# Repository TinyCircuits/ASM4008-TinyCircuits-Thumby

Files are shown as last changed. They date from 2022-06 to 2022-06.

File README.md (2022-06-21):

# ASM4008 TinyCircuits Thumby

The design files are located under design_files/ for the TinyCircuits ASM4008 PCB. *Note: Rev 6 is the latest and current version of Thumby being built and shipped. Early Kickstarter units shipped with Rev 5 Thumby hardware - Rev 6 updates were made during fulfillment to decrease manufacturing and assembly time.* This is a RP2040 board that is programmable using Arduino, Thonny, or any preferred MicroPython IDE. We recommend using our web browser [Thumby Code Editor](https://code.thumby.us/) for MicroPython.

Format is in Cadsoft Eagle format - Eagle version 6.2 was used for the original design.

For more infomation, check out the [Thumby product page](https://tinycircuits.com/thumby) at TinyCircuits.com

Other helpful Thumby Links:

- [Thumby Documentation Site](https://thumby.us/)  
   -  Contribute to Thumby Documentation at the [Thumby Doc Site Repository](https://github.com/TinyCircuits/Thumby-Website)
- [Thumby Code Editor](https://code.thumby.us/)
   - Contrbute to the [Thumby Code Editor Repository](https://github.com/TinyCircuits/TinyCircuits-Thumby-Code-Editor)
- [Thumby Arcade](https://arcade.thumby.us/)
   - Contribute a game to the [Thumby Game Repository](https://github.com/TinyCircuits/TinyCircuits-Thumby-Games)

# License:

Design by TinyCircuits.
All design files are released under the Creative Commons Attribution Share-Alike 3.0 License, see the following link for details: http://creativecommons.org/licenses/by-sa/3.0

All text above must be included in any redistribution or derived design

This project uses designs and concepts developed as part of the Arduino project and the LilyPad project.  The TinyCircuits design files themselves (schematics, PCB and libraries) are not directly derived from these works' design files and have been created new, however the concepts and basic architecture behind the TinyDuino and TinyLily products are derived and we thank the hard work of the organizations below for their contributions to open-source hardware:
  
Original Arduino Uno Design by Team Arduino

LilyPad Arduino Design by Leah Buechley and Sparkfun Electronics

Please support the open-source hardware community

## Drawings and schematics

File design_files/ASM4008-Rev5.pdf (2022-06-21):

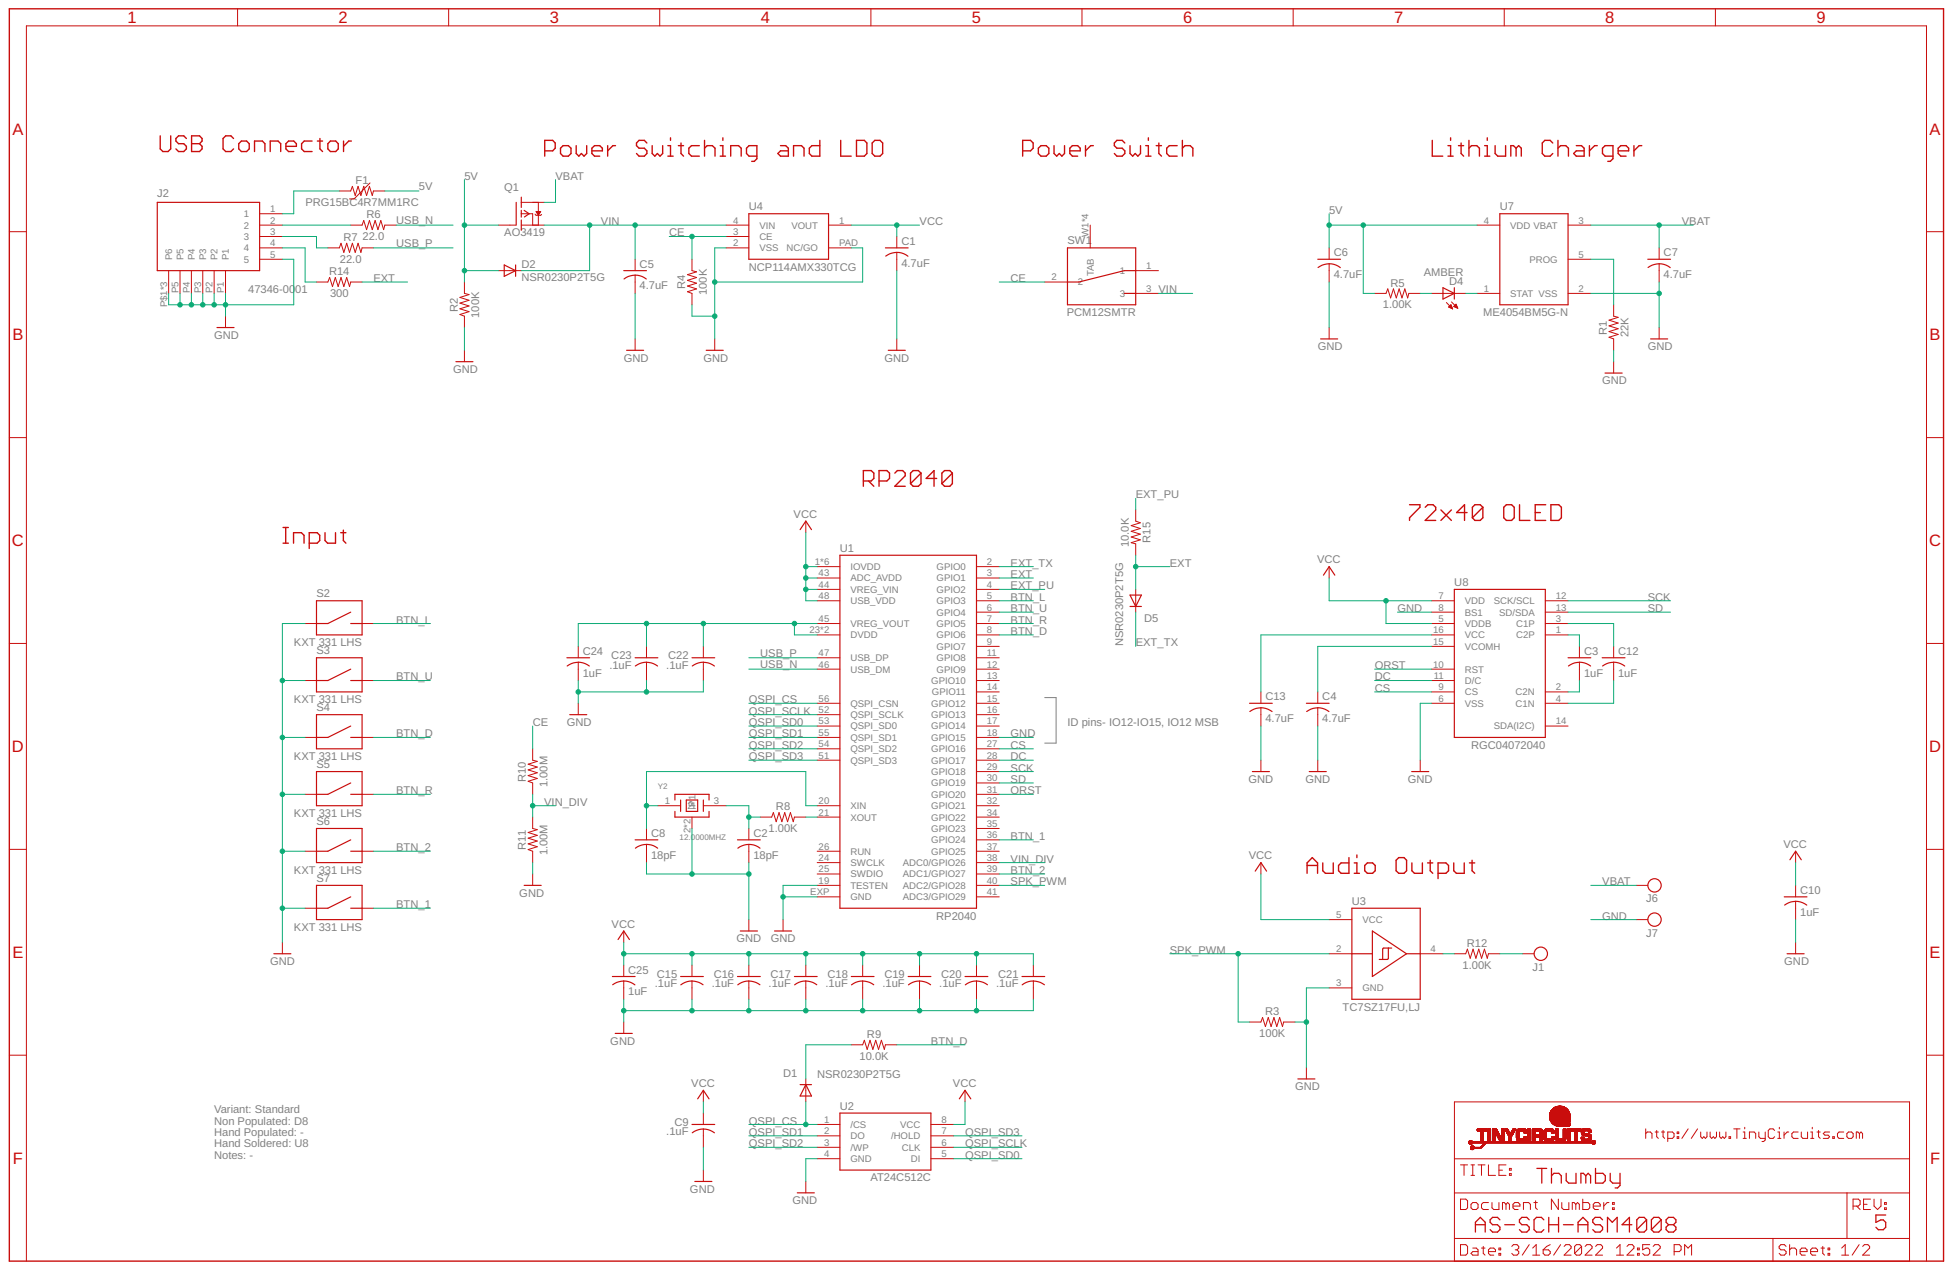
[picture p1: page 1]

Variant: Standard
Non Populated: D8
Hand Populated: - Hand Soldered: U8

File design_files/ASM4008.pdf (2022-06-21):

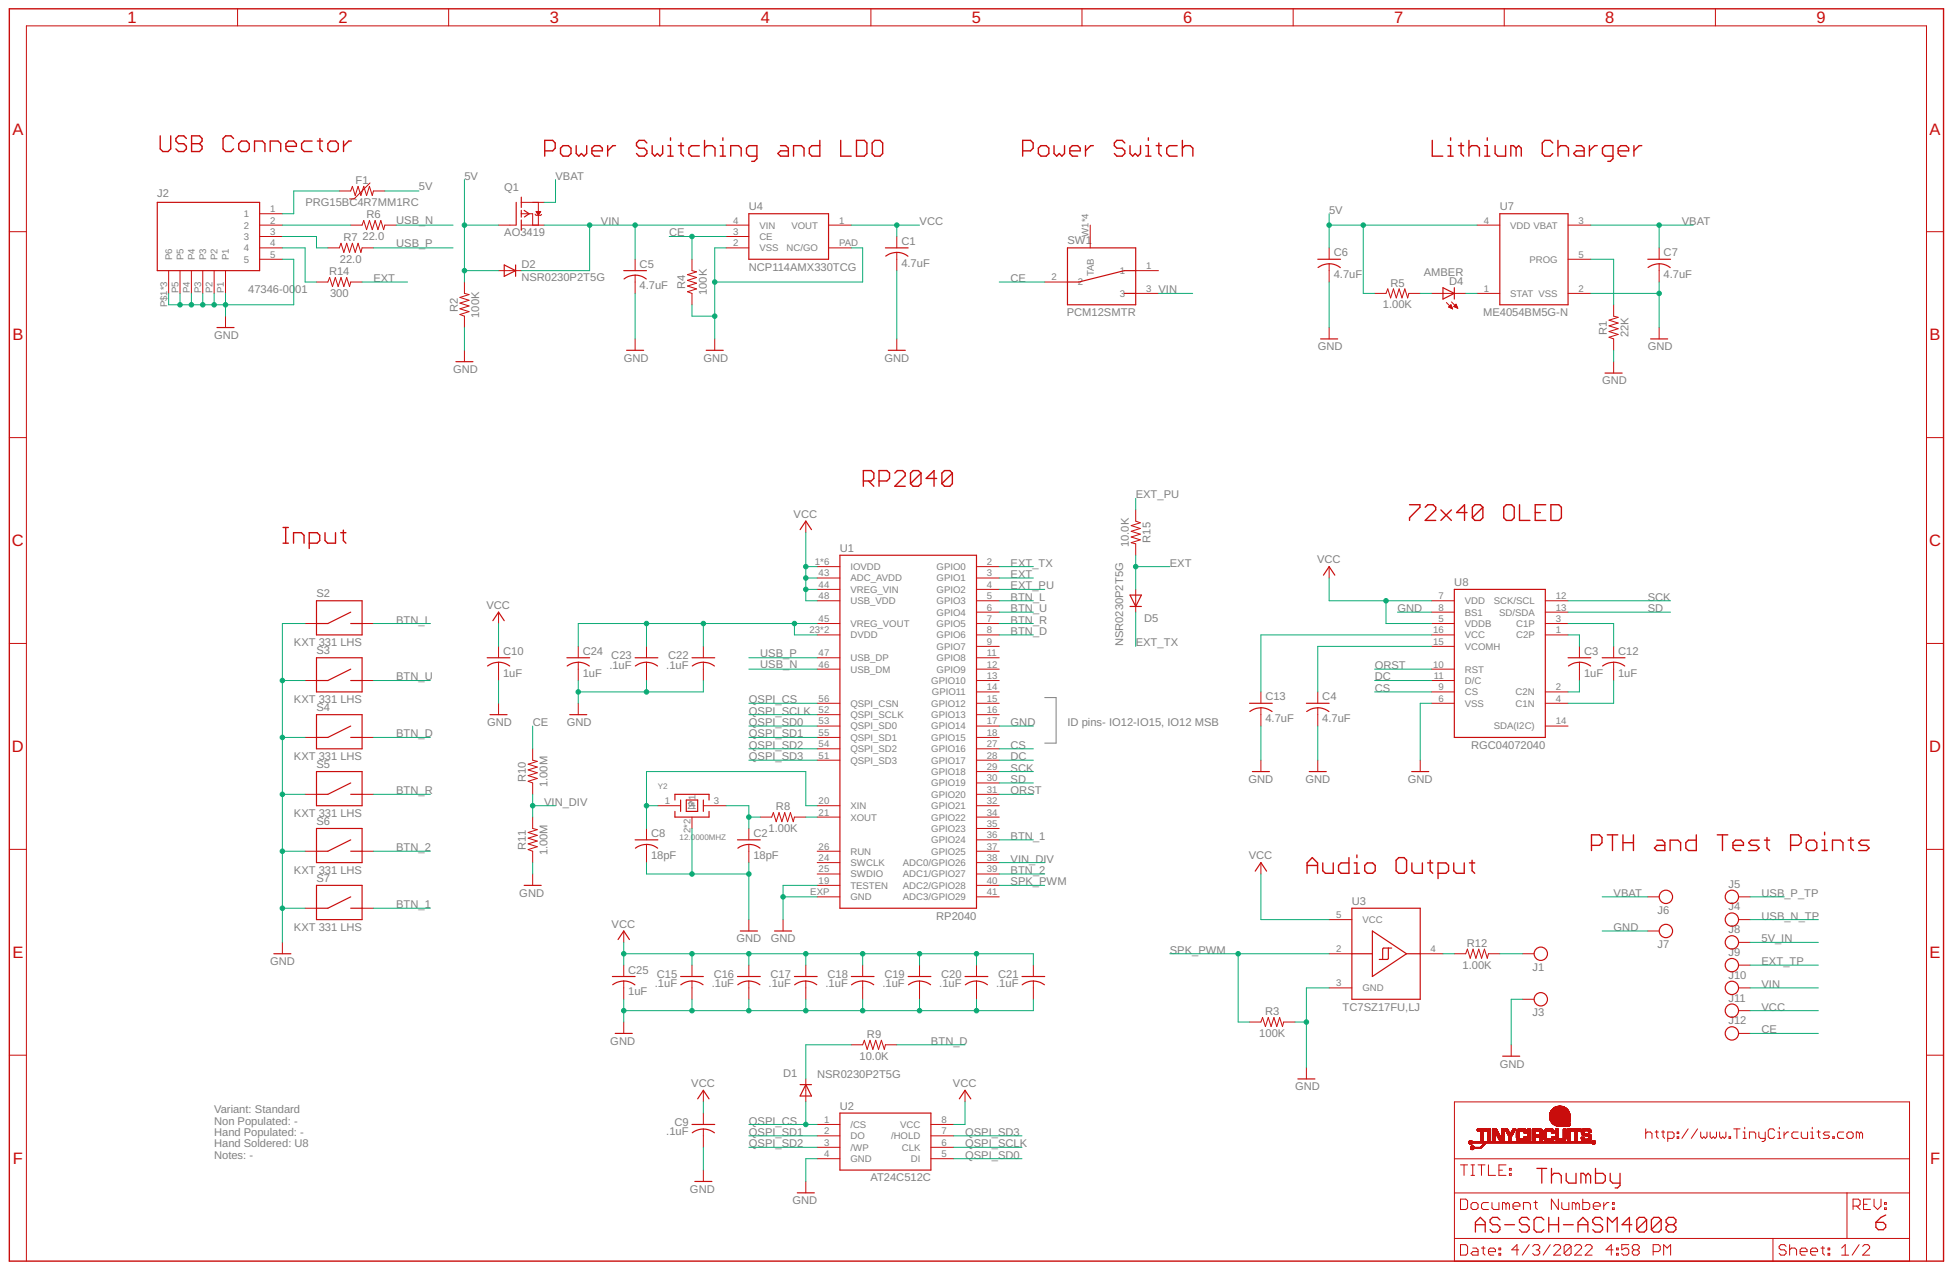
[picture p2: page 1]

Variant: Standard
Non Populated: - Hand Populated: - Hand Soldered: U8

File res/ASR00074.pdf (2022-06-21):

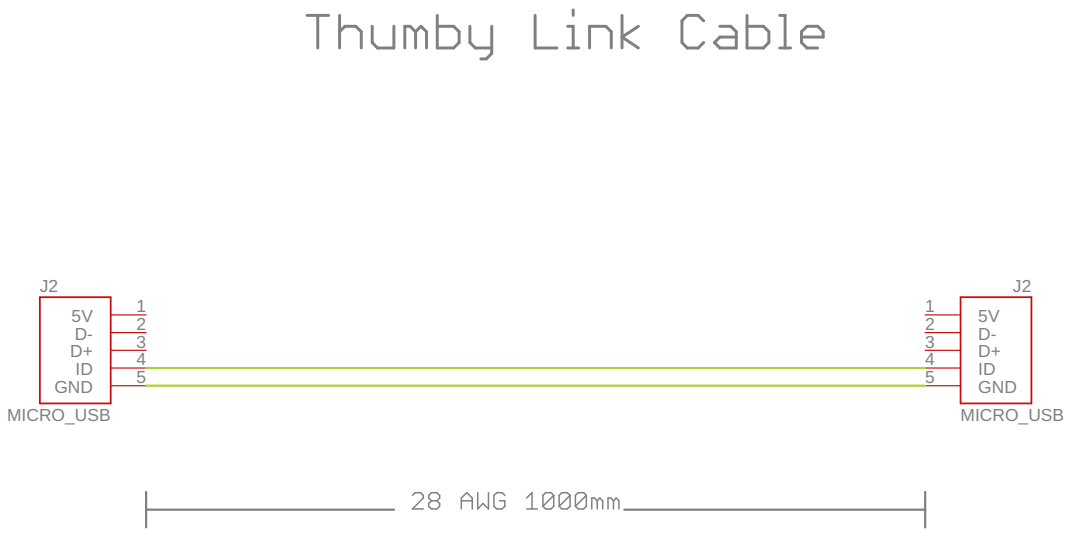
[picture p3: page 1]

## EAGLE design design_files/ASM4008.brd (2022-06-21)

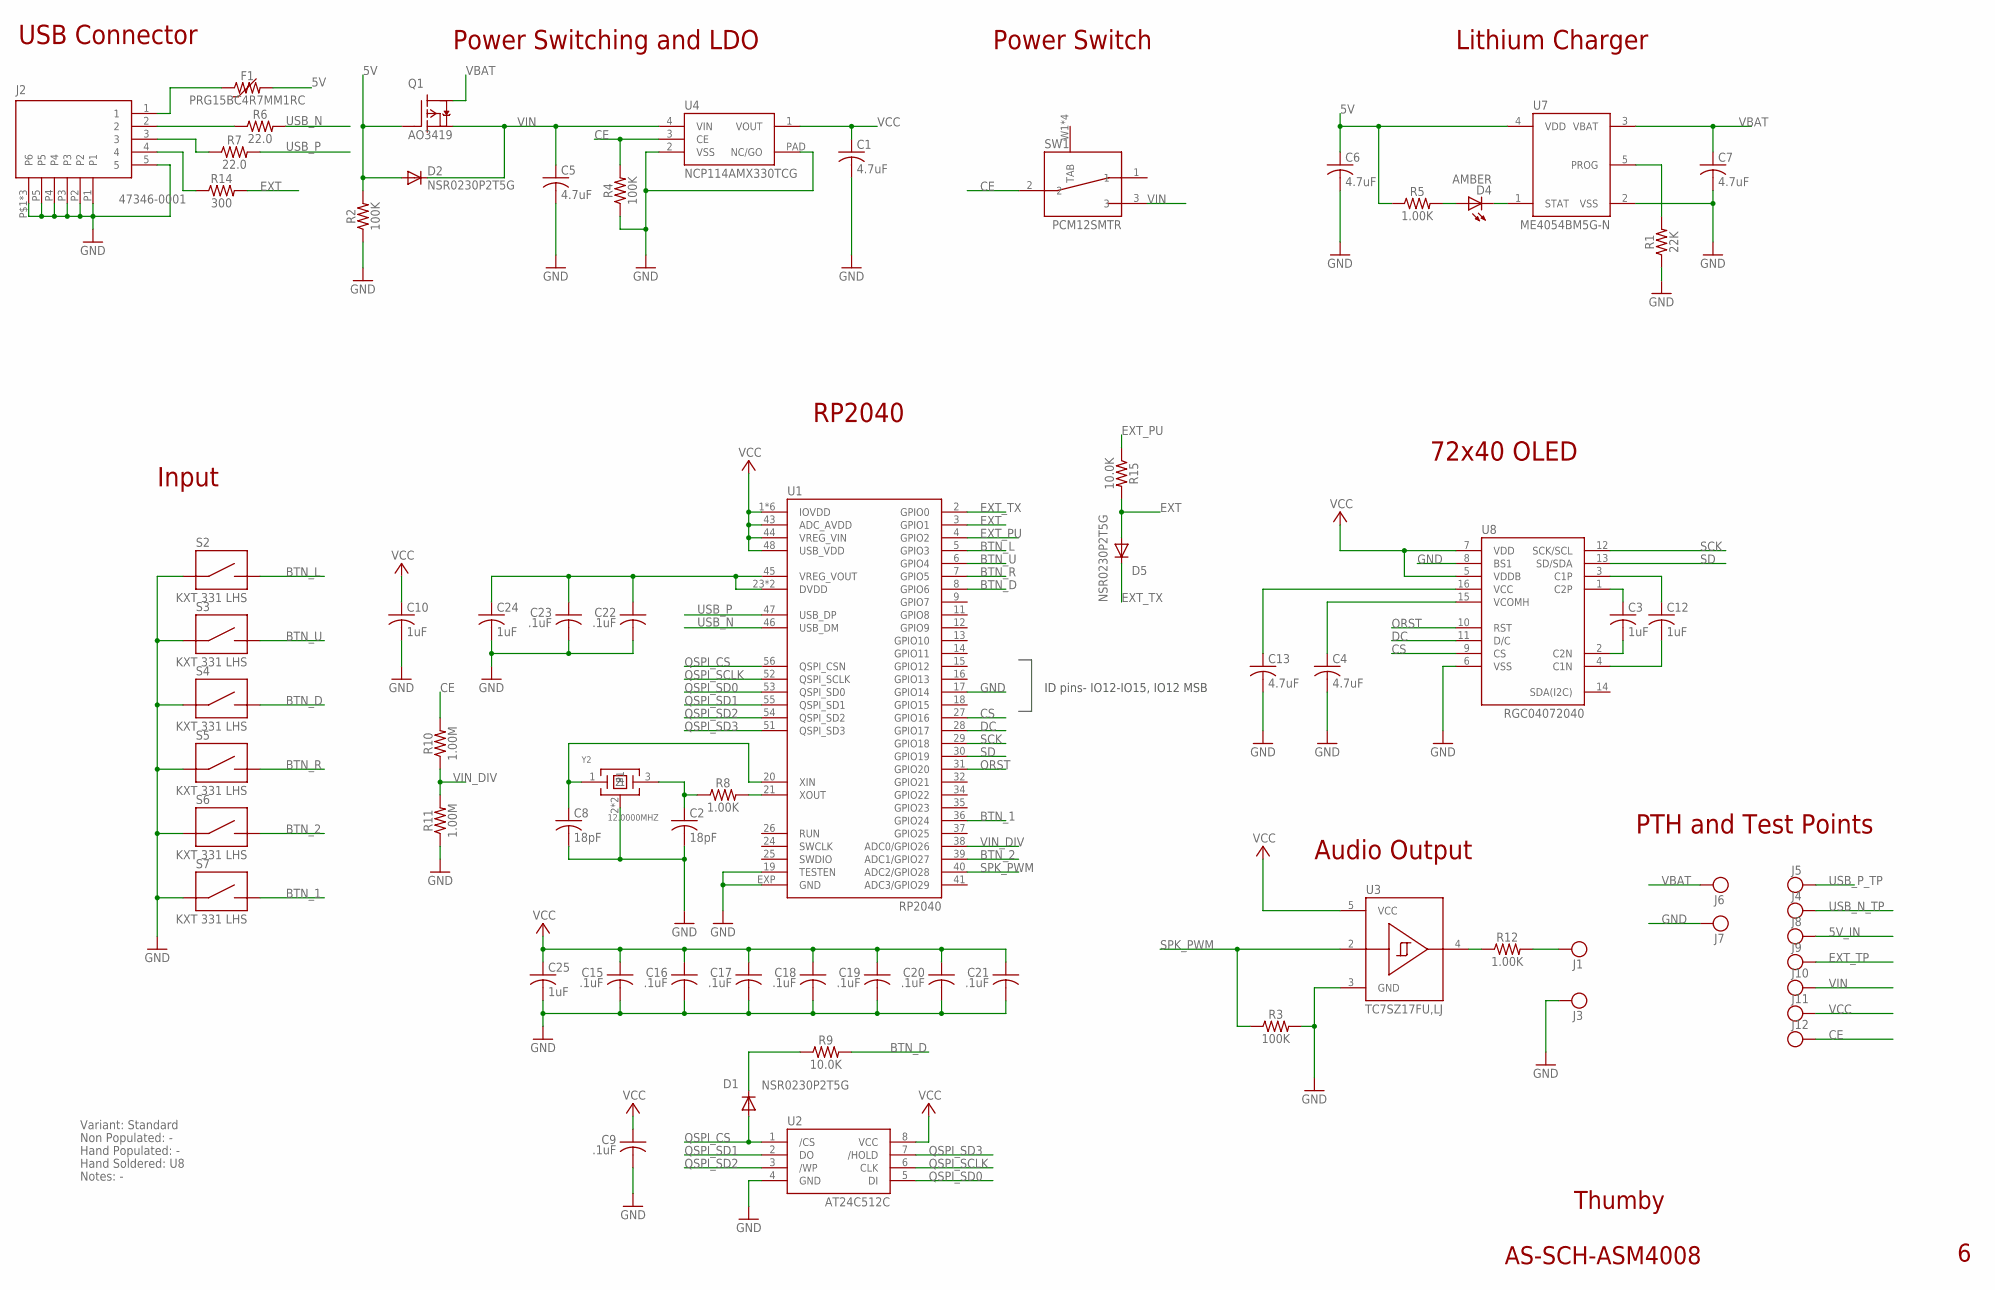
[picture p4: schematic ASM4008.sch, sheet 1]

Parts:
C1, C5: 4.7uF; C0402; PARTNO AS-ITM-00242
C2, C8: 18pF; C0402
C3, C10, C12: 1uF; C0603
C4, C13: 4.7uF; C0603
C6, C7: 4.7uF; C0402
C9, C22, C23: .1uF; C0402
C15, C16, C17, C18, C19, C20, C21: .1uF; C0402; PARTNO AS-ITM-00008
C24, C25: 1uF; C0402
D1, D2, D5: NSR0230P2T5G; SOD-923L
D4: AMBER; 0402_LED
F1: PRG15BC4R7MM1RC; 0402
J1, J3: 2336713-2
J2: 47346-0001; MICRO_USB_TABS
J4, J5, J8, J9, J10, J11, J12: TEST_POINT; TEST_POINT_1MM
J6, J7: PIN_1X.1"; 1X.1"
Q1: AO3419; SOT23A
R1: 22K; 0402
R2, R3, R4: 100K; 0402
R5, R8, R12: 1.00K; 0402
R6, R7: 22.0; 0402
R9, R15: 10.0K; 0402
R10, R11: 1.00M; 0402
R14: 300; 0402
S2, S3, S4, S5, S6, S7: KXT 331 LHS; KXT_LHS_1
SW1: PCM12SMTR; PCM12SMTR_THUMBY
U1: RP2040; QFN56_0.4
U2: AT24C512C; UDFN-8-NP; PARTNO AS-ITM-00628
U3: TC7SZ17FU,LJ; SOT-353-NOPAD; PARTNO AS-ITM-00647
U4: NCP114AMX330TCG; 4-UFDN
U7: ME4054BM5G-N; SOT-23
U8: RGC04072040; OLED_042
Y2: 12.0000MHZ; CRYSTAL_2.5X2MM_4SMD

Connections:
5V: C6.1, D2.A, F1.2, Q1.B (G), R2.2, R5.1, U7.4 (VDD)
5V_IN: F1.1, J2.1, J8.P$1
BTN_1: S7.2, U1.36 (GPIO24)
BTN_2: S6.2, U1.39 (ADC1/GPIO27)
BTN_D: R9.2, S4.2, U1.8 (GPIO6)
BTN_L: S2.2, U1.5 (GPIO3)
BTN_R: S5.2, U1.7 (GPIO5)
BTN_U: S3.2, U1.6 (GPIO4)
CE: J12.P$1, R4.2, R10.2, SW1.2, U4.3 (CE)
CS: U1.27 (GPIO16), U8.9 (CS)
DC: U1.28 (GPIO17), U8.11 (D/C)
EXT: D5.A, R14.2, R15.2, U1.3 (GPIO1)
EXT_PU: R15.1, U1.4 (GPIO2)
EXT_TP: J2.4, J9.P$1, R14.1
EXT_TX: D5.C, U1.2 (GPIO0)
GND: C1.2, C2.2, C4.2, C5.2, C6.2, C7.2, C8.2, C9.2, C10.2, C13.2, C15.2, C16.2, C17.2, C18.2, C19.2, C20.2, C21.2, C22.2, C23.2, C24.2, C25.2, J2.5, J2.P1, J2.P2, J2.P3, J2.P4, J2.P5, J2.P6, J2.P$1 (P6), J2.P$2 (P6), J3.P$1, J7.1, R1.1, R2.1, R3.2, R4.1, R11.1, S2.1, S3.1, S4.1, S5.1, S6.1, S7.1, U1.17 (GPIO14), U1.19 (TESTEN), U1.EXP (GND), U2.4 (GND), U3.3 (GND), U4.2 (VSS), U4.PAD (NC/GO), U7.2 (VSS), U8.6 (VSS), U8.8 (BS1), Y2.2 (P1), Y2.4 (P1)
unnamed: D4.2 (C), U7.1 (STAT)
unnamed: D4.1 (A), R5.2
unnamed: R1.2, U7.5 (PROG)
unnamed: D1.C, R9.1
unnamed: J1.P$1, R12.2
unnamed: C22.1, C23.1, C24.1, U1.23 (DVDD), U1.45 (VREG_VOUT), U1.50 (DVDD)
unnamed: R8.2, U1.21 (XOUT)
unnamed: C8.1, U1.20 (XIN), Y2.1
unnamed: C2.1, R8.1, Y2.3 (2)
unnamed: R12.1, U3.4 (Y)
unnamed: C4.1, U8.15 (VCOMH)
unnamed: C13.1, U8.16 (VCC)
unnamed: C3.1, U8.1 (C2P)
unnamed: C12.1, U8.3 (C1P)
unnamed: C3.2, U8.2 (C2N)
unnamed: C12.2, U8.4 (C1N)
ORST: U1.31 (GPIO20), U8.10 (RST)
QSPI_CS: D1.A, U1.56 (QSPI_CSN), U2.1 (/CS)
QSPI_SCLK: U1.52 (QSPI_SCLK), U2.6 (CLK)
QSPI_SD0: U1.53 (QSPI_SD0), U2.5 (DI)
QSPI_SD1: U1.55 (QSPI_SD1), U2.2 (DO)
QSPI_SD2: U1.54 (QSPI_SD2), U2.3 (/WP)
QSPI_SD3: U1.51 (QSPI_SD3), U2.7 (/HOLD)
SCK: U1.29 (GPIO18), U8.12 (SCK/SCL)
SD: U1.30 (GPIO19), U8.13 (SD/SDA)
SPK_PWM: R3.1, U1.40 (ADC2/GPIO28), U3.2 (A)
USB_N: R6.2, U1.46 (USB_DM)
USB_N_TP: J2.2, J4.P$1, R6.1
USB_P: R7.2, U1.47 (USB_DP)
USB_P_TP: J2.3, J5.P$1, R7.1
VBAT: C7.1, J6.1, Q1.C (D), U7.3 (VBAT)
VCC: C1.1, C9.1, C10.1, C15.1, C16.1, C17.1, C18.1, C19.1, C20.1, C21.1, C25.1, J11.P$1, U1.1 (IOVDD), U1.10 (IOVDD), U1.22 (IOVDD), U1.33 (IOVDD), U1.42 (IOVDD), U1.43 (ADC_AVDD), U1.44 (VREG_VIN), U1.48 (USB_VDD), U1.49 (IOVDD), U2.8 (VCC), U3.5 (VCC), U4.1 (VOUT), U8.5 (VDDB), U8.7 (VDD)
VIN: C5.1, D2.C, J10.P$1, Q1.E (S), SW1.3, U4.4 (VIN)
VIN_DIV: R10.1, R11.2, U1.38 (ADC0/GPIO26)

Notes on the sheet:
Thumby
AS-SCH-ASM4008
Lithium Charger
Power Switching and LDO
72x40 OLED
RP2040
Variant: Standard
Non Populated: -
Hand Populated: -
Hand Soldered: U8
Notes: -
USB Connector
Power Switch
Input
Audio Output
ID pins- IO12-IO15, IO12 MSB
PTH and Test Points

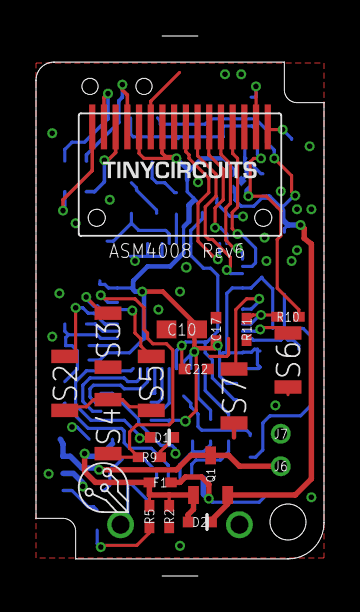
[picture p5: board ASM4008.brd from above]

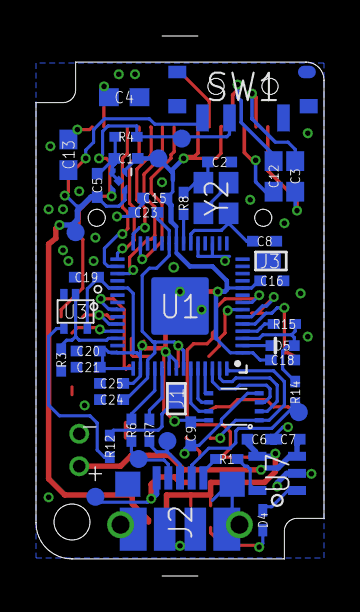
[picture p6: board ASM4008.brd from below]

Board: 2 copper layers, 16.0 x 30.0 mm, 70 parts (48 on the bottom side), 50 nets.

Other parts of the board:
U$1: DOCFIELD-TINYCIRCUITS-PCB

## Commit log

2022-06-21 design files
    [ASM4008-Rev5.brd, ASM4008-Rev5.sch, ASM4008.brd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]
2022-06-21 Add Thumby STL
2022-06-21 Link Cable connection
2023-02-08 make stl easier to download
2023-02-09 Update Thumby stl zip to include separated files
